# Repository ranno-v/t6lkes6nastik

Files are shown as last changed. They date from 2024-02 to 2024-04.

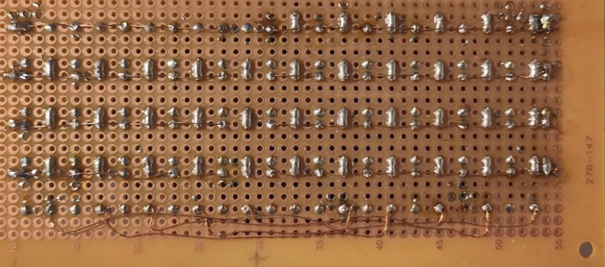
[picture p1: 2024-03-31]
klahvistiku_foto.png

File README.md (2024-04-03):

## Kirjeldus
See on gümnaasiumiastme praktilise töö "Ajaloolise kirjelduse põhjal Arduino UNO elektroonikaplatvormil loodud väike eesti-inglise-saksa-vene tõlkesõnastik" raames valminud projekti iseseisvaks sooritamiseks vajalike failide varamu. Siin asub Arduinole vajalik kood, korpuse ja nuppude 3D-printimiseks vajalikud STL-failid, joonised, tabelid, juhised jne. _Varamu on valmimisel._



## Komponendid
Seadme ehitamiseks vajalikud komponendid on Arduino Uno plaat, 16-segmendiline LCD-moodul DM8BA10, perforeeritud prototüüpplaat mõõtmetega vähemalt 45 x 20 auku (iga augu vahe 2.54 mm), 10 pistikutega juhet pikkusega vähemalt 20 cm (või 20 pistikuga juhet pikkusega vähemalt 10 cm, mille teises otsas on isoleerita traat), 44 mikrolülitit, 9-voldine patarei koos pesaga, 5,5 mm x 2,1 mm alalisvoolupistik (nn _barrel jack_), vasktraat, jootetina, 4 väikest kruvi, kiirliim, lüliti ja PLA-filament. Vajalikud tööriistad on 3D-printer, jootekolb, arvuti, USB-A/USB-B kaabel, akutrell ja lõikeriist, millega saab lõigata läbi prototüüpplaadi plastiku. Veel on vaja viisi seadmele klahvide märkimiseks, selleks sobib näiteks püsimarker või kleepepaber ja printer.

## Juhised
Esmalt lõigake 7 juhet pooleks ja puhastage lõigatud otsad isoleermaterjalist. Seejärel jootke mikrolülitid ja vasktraat prototüüpplaadi külge nii, nagu on näidatud joonistel klahvistiku_skeem.png ja klahvistiku_foto.png. Skeemil on vasktraat kujutatud punaste joontena ja jootetina roheliste joontena, lülitid pruunide ristkülikutena. Jootke juhtmete lõigatud otsad nummerdatud punaste ringidega märgitud kontaktide külge nii, et juhtmed väljuksid poolelt, kus pole kontakte. Numbritega on märgitud, millisesse Arduiino siini tuleb juhtme pistik panna. Lõigake perforeeritud plaadist ristkülik nii, et selle mõõtmed oleksid 45 x 20 auku (see ristkülik on skeemil märgitud punktiirjoonega). Asetage juhtmed skeemil märgitud siinidesse.

Lõigake pooleks veel 2 juhet ja puhastage lõigatud otsad isoleermaterjalist. Jootke juhtmed LCD-ekraani klemmide V+, G, D, WR ja CS külge ja asetage pistikud vastavalt siinidesse 5V, GND, A2, A1 ja A0.

Printige antud STL-failid välja. Kinnitage "klambrid" superliimiga plaadi külge nii, nagu on näidatud alloleval joonisel. Kinnitage LCD-ekraan superliimiga korpuse kaane külge. Puurige 2 mm puuriteraga läbi vertikaalsete osade ning kaane vastavate punktide augud nii, et mikrolülitid oleks kaanes olevate avadega kohakuti. Asetage klahvid avadesse ja kinnitage klambrid kruvidega kaane külge. Jootke 9V patarei alles jäänud juhtmetega läbi lüliti alalisvoolupistiku külge, tehke kaane sisse lüliti jaoks sobiv ava ja kinnitage lüliti kaane külge. Märgistage klahvid, selleks on üks võimalus printida välja fail labels.pdf, lõigata sildid mööda jooni nelja ribana välja ja liimida need kaane külge vastavate klahvide kohale. 



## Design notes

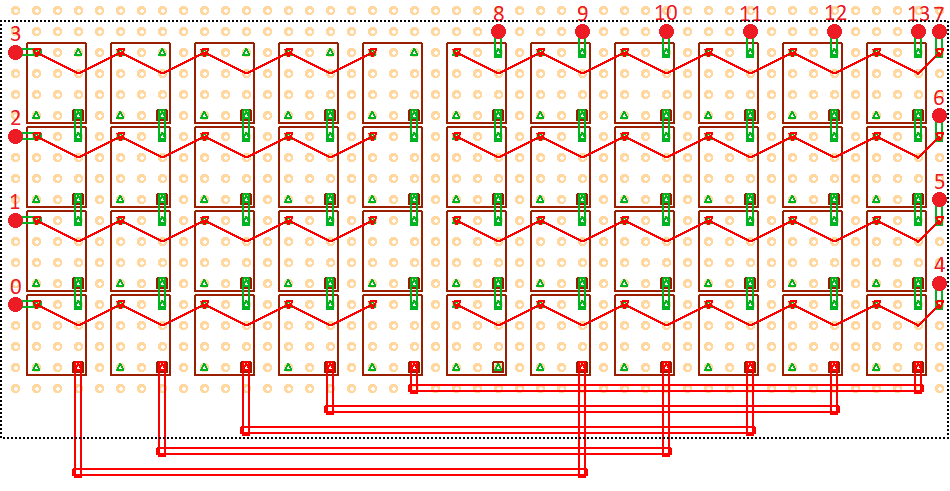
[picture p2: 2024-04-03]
kastiga_skeem.png

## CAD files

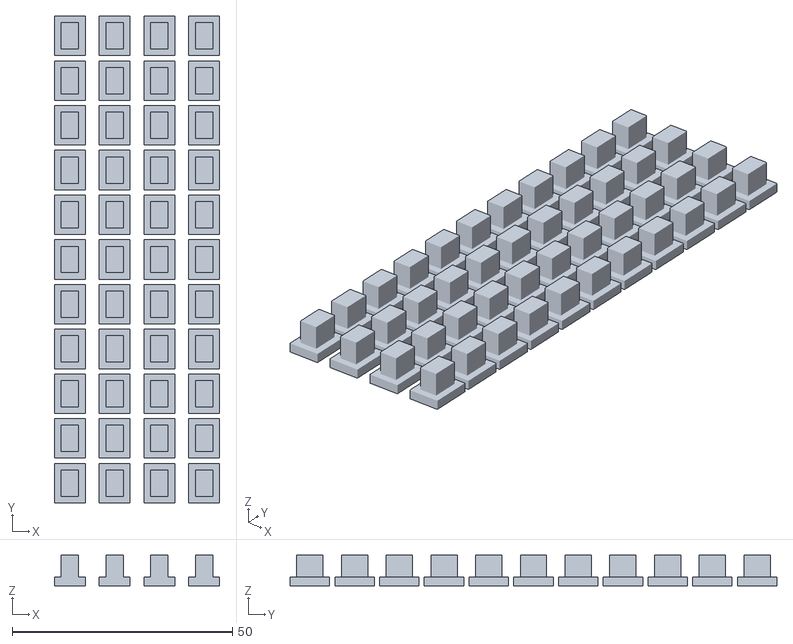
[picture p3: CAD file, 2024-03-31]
klahvid.stl
37.5 x 110.6 x 7.00

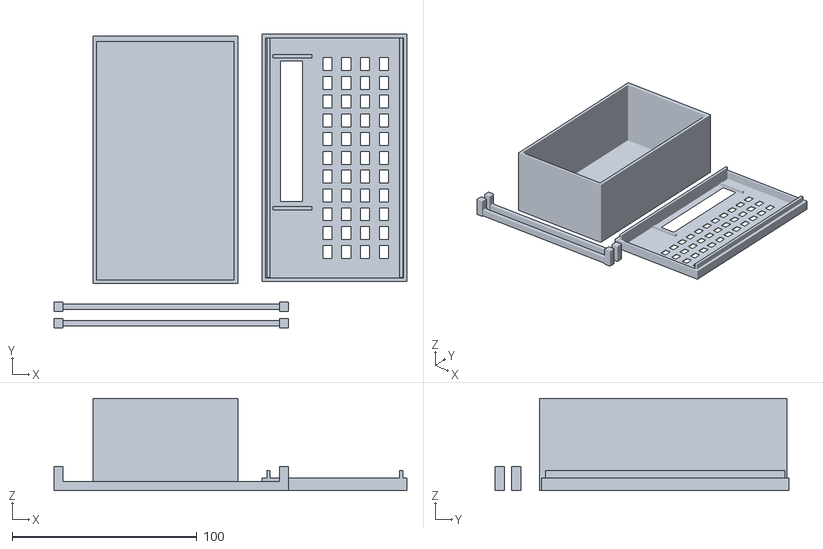
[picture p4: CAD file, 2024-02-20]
korpus.stl
191.0 x 159.0 x 50.0

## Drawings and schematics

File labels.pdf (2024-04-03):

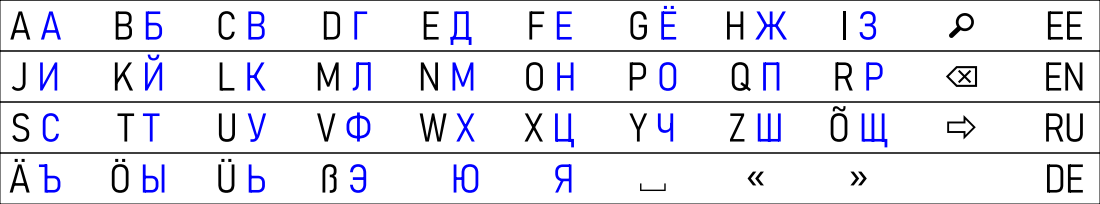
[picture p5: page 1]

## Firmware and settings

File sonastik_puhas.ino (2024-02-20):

#include <Keypad.h>
#define PGMT(pgm_ptr) ( reinterpret_cast< const __FlashStringHelper * >( pgm_ptr )

/*
=-=-=-=-=-=-=-=-=-=-=-=-=-=-=-=-=-=-=-=-=-=-=-=-=-=-=-=-=-=-=-=-=-=-=-=-=-=-=
    Arduino demo/driver for HT1622-based 16 segment LCDs

    Copyright (c) 2015-2021 Martin F. Falatic
    
    Licensed under the Apache License, Version 2.0 (the "License");
    you may not use this file except in compliance with the License.
    You may obtain a copy of the License at
    
        http://www.apache.org/licenses/LICENSE-2.0
    
    Unless required by applicable law or agreed to in writing, software
    distributed under the License is distributed on an "AS IS" BASIS,
    WITHOUT WARRANTIES OR CONDITIONS OF ANY KIND, either express or implied.
    See the License for the specific language governing permissions and
    limitations under the License.

=-=-=-=-=-=-=-=-=-=-=-=-=-=-=-=-=-=-=-=-=-=-=-=-=-=-=-=-=-=-=-=-=-=-=-=-=-=-=
Arduino is little-endian
H162x commands and addresses are MSB-first (3 bit mode + 9 bit command code)
Note that the very last bit is X (don't care)
Data is LSB-first, in address-sequential 4-bit nibbles as desired.
=-=-=-=-=-=-=-=-=-=-=-=-=-=-=-=-=-=-=-=-=-=-=-=-=-=-=-=-=-=-=-=-=-=-=-=-=-=-=
*/

//=-=-=-=-=-=-=-=-=-=-=-=-=-=-=-=-=-=-=-=-=-=-=-=-=-=-=-=-=-=-=-=-=-=-=-=-=-=-=
// Helper functions and variables
//=-=-=-=-=-=-=-=-=-=-=-=-=-=-=-=-=-=-=-=-=-=-=-=-=-=-=-=-=-=-=-=-=-=-=-=-=-=-=
#define ARRAY_SIZE(x) ((sizeof x) / (sizeof *x))

//=-=-=-=-=-=-=-=-=-=-=-=-=-=-=-=-=-=-=-=-=-=-=-=-=-=-=-=-=-=-=-=-=-=-=-=-=-=-=
// HT162x commands (Start with 0b100, ends with one "don't care" byte)
#define  CMD_SYS_DIS  0x00  // SYS DIS    (0000-0000-X) Turn off system oscillator, LCD bias gen [Default]
#define  CMD_SYS_EN   0x01  // SYS EN     (0000-0001-X) Turn on  system oscillator
#define  CMD_LCD_OFF  0x02  // LCD OFF    (0000-0010-X) Turn off LCD display [Default]
#define  CMD_LCD_ON   0x03  // LCD ON     (0000-0011-X) Turn on  LCD display
#define  CMD_RC_INT   0x18  // RC INT     (0001-10XX-X) System clock source, on-chip RC oscillator
#define  CMD_BIAS_COM 0x29  // BIAS & COM (0010-10X1-X) 1/3 bias, 4 commons // HT1621 only

#define  HT1622_ADDRS 0x40  // HT1622 has 64 possible 4-bit addresses

#define CS   14 // Active low
#define WR   15 // Active low
#define DATA  16

#define LSB_FORMAT  true
#define MSB_FORMAT  false

#define SETUP_DELAY_USECS 1
#define HOLD_DELAY_USECS  1
#define WRITE_DELAY_USECS 2  // Tclk min. on data sheet - overhead is more than this at low clock speeds
#define RESET_DELAY_USECS 1000  // Not strictly necessary

#define NUM_DIGITS  10

const uint8_t digitAddr[NUM_DIGITS] = {
  0x24, 0x20, 0x1C, 0x18, 0x14, 0x10, 0x0C, 0x08, 0x04, 0x00
};

const uint16_t PROGMEM SegCharDataLSBfirst[] = {
  0x0000, 0x0000, 0x122D, 0x0000, 0x0000, 0x0000, 0x0000, 0xCC0D, //  !"#$%&'
  0x0082, 0x2100, 0xA3A3, 0x8221, 0x0100, 0x8001, 0x0800, 0x0180, // ()*+,-./
  0x5C5C, 0x1A28, 0x9C59, 0x985D, 0xC045, 0xD81D, 0xDC1D, 0x1054, // 01234567
  0xDC5D, 0xD85D, 0x8800, 0x0000, 0x8809, 0x0000, 0x0000, 0x0000, // 89:;<=>?
  0x0000, 0x11D5, 0x1A3D, 0x4E28, 0x097C, 0x185D, 0xD271, 0x5410, // @ABCDEFG
  0x9D19, 0x45C4, 0x15C4, 0xC67C, 0x0174, 0x0000, 0x0000, 0x9C1D, // HIJKLMNO
  0x5454, 0xD155, 0x0000, 0x549D, 0xC045, 0x1C1C, 0x4E6E, 0x4E6C, // PQRSTUVW
  0x0000, 0xCE44, 0x23A2, 0x0000, 0x2002, 0x0000, 0x060D, 0x0808, // XYZ[\]^_
  0x0000, 0xD455, 0x1A7D, 0x5C18, 0x1A7C, 0xDC19, 0xD411, 0x5C1D, // `abcdefg
  0xC445, 0x1A38, 0x0C4C, 0xC482, 0x4C08, 0x64C4, 0x6446, 0x5C5C, // hijklmno
  0xD451, 0x5C5E, 0xD453, 0xD81D, 0x1230, 0x4C4C, 0x4580, 0x4546, // pqrstuvw
  0x2182, 0xC84D, 0x1998, 0x0000, 0x0000, 0x0000, 0x9CAD, 0x0000, // xyz{|}~
};

//=-=-=-=-=-=-=-=-=-=-=-=-=-=-=-=-=-=-=-=-=-=-=-=-=-=-=-=-=-=-=-=-=-=-=-=-=-=-=
char * valToHex(int val, int prec, const char * prefix) {
      static char fmt[32], output[32];
      sprintf(fmt, "%s%%0%dX", prefix, prec);
      sprintf(output, fmt, val);
      return output;
}

//=-=-=-=-=-=-=-=-=-=-=-=-=-=-=-=-=-=-=-=-=-=-=-=-=-=-=-=-=-=-=-=-=-=-=-=-=-=-=
// Send up to 16 bits, MSB (default) or LSB
//=-=-=-=-=-=-=-=-=-=-=-=-=-=-=-=-=-=-=-=-=-=-=-=-=-=-=-=-=-=-=-=-=-=-=-=-=-=-=
void HT162x_SendBits(uint16_t data, uint8_t bits, boolean LSB_FIRST = MSB_FORMAT)
{
  // Data is shifted out bitwise, either LSB-first or MSB-first.
  // The mask is used to isolate the bit being transmitted.

  uint16_t mask = LSB_FIRST ? 1 : 1 << bits-1;

  for (uint8_t i = bits; i > 0; i--)
  {
    delayMicroseconds(WRITE_DELAY_USECS);
    digitalWrite(WR, LOW);
    data & mask ? digitalWrite(DATA, HIGH) : digitalWrite(DATA, LOW);
    delayMicroseconds(WRITE_DELAY_USECS);
    digitalWrite(WR, HIGH);
    delayMicroseconds(HOLD_DELAY_USECS);
    LSB_FIRST ? data >>= 1 : data <<= 1;
  }
}

//=-=-=-=-=-=-=-=-=-=-=-=-=-=-=-=-=-=-=-=-=-=-=-=-=-=-=-=-=-=-=-=-=-=-=-=-=-=-=
void HT162x_Command(uint8_t cmd)
{
  delayMicroseconds(SETUP_DELAY_USECS);
  digitalWrite(CS, LOW);
  delayMicroseconds(SETUP_DELAY_USECS);
  HT162x_SendBits(0b100, 3);
  HT162x_SendBits(cmd, 8);
  HT162x_SendBits(1, 1);
  delayMicroseconds(SETUP_DELAY_USECS);
  digitalWrite(CS, HIGH);
}

//=-=-=-=-=-=-=-=-=-=-=-=-=-=-=-=-=-=-=-=-=-=-=-=-=-=-=-=-=-=-=-=-=-=-=-=-=-=-=
void HT162x_WriteData(uint8_t addr, uint16_t sdata, uint8_t bits = 4)
{
  // Note: bits needs to be a multiple of 4 as data is in nibbles
  delayMicroseconds(SETUP_DELAY_USECS);
  digitalWrite(CS, LOW);
  delayMicroseconds(SETUP_DELAY_USECS);
  HT162x_SendBits(0b101, 3);
  HT162x_SendBits(addr, 6);
  for (int n = (bits/4)-1; n >= 0; n--) {
    uint16_t nib = (sdata & (0xf) << 4*n) >> (4*n);
    HT162x_SendBits(nib, 4, LSB_FORMAT);
  }
  delayMicroseconds(SETUP_DELAY_USECS);
  digitalWrite(CS, HIGH);
}

void AllElements(uint8_t state)
{
  for (uint8_t addr = 0; addr < HT1622_ADDRS; addr++)
  {
    HT162x_WriteData(addr, (state ? 0xF : 0x0), 4);
  }
}

void AllSegments(uint8_t state)
{
  for (uint8_t pos = 0; pos < NUM_DIGITS; pos++)
  {
    HT162x_WriteData(digitAddr[pos], (state ? 0xFFFF : 0x0000), 16);
  }
}

void Display(char word[], int word_len, int position)
{
  for (int n = 0; n + position < word_len && n < 10 ; n++)
  {
    HT162x_WriteData(digitAddr[n], pgm_read_word_near(SegCharDataLSBfirst + (int)word[n + position] - 32), 16);
  }

}

// END OF LCD DRIVER FUNCTIONS

const byte rows = 8;  // eight rows
const byte cols = 6;  // six columns
char keys[rows][cols] = {
  {  1,  2,  3,  4,  5,  6, },
  { 10, 11, 12, 13, 14, 15, },
  { 19, 20, 21, 22, 23, 24, },
  { 28, 29, 30, 31, 32, 33, },

  {  7,  8,  9,  37,  41,  0, },
  { 16, 17, 18,  38,  42,  0, },
  { 25, 26, 27,  39,  43,  0, },
  { 34, 35, 36,  40,  44,  0, },
};
byte rowPins[rows] = { 13, 12, 11, 10, 9, 8, 7, 6, };        // connect to the row pinouts of the keypad
byte colPins[cols] = { 5, 4, 3, 2, 1, 0, };  // connect to the column pinouts of the keypad
Keypad keyboard = Keypad(makeKeymap(keys), rowPins, colPins, rows, cols);

const char latin[34] =    "abcdefghijklmnopqrstuvwxyz~AOUS   ";
const char cyrillic[34] = "aBbGDeHZ3IJkLmhoPpctyFxCTWV\"Y\'EKQ ";

const char PROGMEM estonian[] = "\naasta\nabi\naeg\naga\nainult\nainus\naitama\najal\najama\naken\naktsia\nalati\nalgama\nalgus\nall\nalla\nalles\nalus\nalustama\namet\nandma\nandmed\naru\narvama\nasi\nastuma\nasuma\naugust\nauto\navama\nedasi\neelmine\nees\neesmArk\neest\neesti\neestlane\nega\nehitama\nehk\nei\neile\neks\nelama\nelu\nema\nenam\nendine\nenne\nent\nerakond\nerinev\neriti\nesimees\nesimene\nesitama\net\nette\nettev~te\nfilm\nfirma\nhakkama\nhea\nheitma\nhetk\nhiljem\nhind\nhing\nhinnang\nhoidma\nhommik\nhoopis\nhulk\nhuvi\nhAsti\nhAAl\niga\nikka\nikkagi\nilm\nilma\nilmselt\nilmuma\nilus\ninimene\nisa\nise\nisegi\nistuma\nja\njah\njalg\njaoks\njooksma\njooksul\nju\njuba\njuhataja\njuht\njuhtuma\njumal\njust\njutt\njuurde\njuures\nj~ud\nj~udma\njAlle\njArel\njArele\njArgi\njArgmine\njAtkama\njAtma\njAAma\nka\nkaasa\nkaduma\nkaks\nkandma\nkaotama\nkartma\nkas\nkasutama\nkasvama\nkeegi\nkeel\nkeha\nkell\nkes\nkiiresti\nkindel\nkindlasti\nkinni\nkinnitama\nkiri\nkirjutama\nkodu\nkoer\nkogu\nkohalik\nkohe\nkoht\nkohta\nkohus\nkokku\nkolm\nkolmas\nkool\nkoos\nkord\nkorraldama\nkorter\nkostma\nkroon\nkuhu\nkui\nkuid\nkuidagi\nkuidas\nkuigi\nkuna\nkunagi\nkuni\nkus\nkust\nkutsuma\nkuu\nkuulama\nkuulma\nkuuluma\nk~ige\nk~ik\nk~rge\nk~rval\nk~rvale\nkAima\nkAsi\nkUll\nkUlm\nkUmme\nkUsima\nkUsimus\nlaev\nlahkuma\nlahti\nlangema\nlaps\nlaskma\nlaud\nlausuma\nleidma\nleping\nligi\nlihtsalt\nliiga\nliige\nliikuma\nliit\nlinn\nlisa\nlisama\nlooma\nlootma\nlubama\nlugema\nlugu\nl~petama\nl~pp\nl~ppema\nl~puks\nlAbi\nlOOma\nmaa\nmaailm\nmagama\nmaha\nmaja\nmaksma\nmeel\nmeeldima\nmeenutama\nmees\nmeri\nmets\nmiks\nmiljon\nmilline\nmina\nminema\nmingi\nmis\nmiski\nmitte\nmitu\nmuidu\nmuidugi\nmust\nmuu\nmuutma\nmuutuma\nm~istma\nm~lema\nm~ni\nm~te\nm~tlema\nmAletama\nmAng\nmAngima\nmArkama\nmArkima\nmArts\nmOOda\nmUUma\nnaerma\nnagu\nnaine\nneli\nnii\nniisugune\nnimetama\nnimi\nning\nnoor\nnoormees\nn~nda\nn~udma\nn~ukogu\nnAdal\nnAgema\nnAgu\nnAima\nnAitama\nnAiteks\nnUUd\nolema\nolev\nolukord\noluline\noma\nomanik\nometi\nootama\nosa\noskama\nostma\notsa\notse\notsima\notsus\notsustama\npaar\npaistma\npakkuma\npalju\npalk\npaluma\npanema\npank\nparem\nparim\npea\npeaaegu\npeale\npeaminister\npidama\npiir\npikk\npilk\npilt\npisut\npoeg\npoiss\npoliitiline\npolitsei\npool\npoole\npraegu\npraegune\npresident\nprobleem\nprotsent\npuhas\npuhul\npunane\npuu\np~hjus\npAev\npArast\npAris\npAAsema\npOOrama\npOOrduma\npUUdma\nraamat\nraha\nrahvas\nraske\nriigikogu\nriik\nringi\nrohkem\nruum\nrAAkima\nsaama\nsaatma\nsama\nsamas\nsamm\nsamuti\nsattuma\nseadus\nseal\nsealt\nsee\nsein\nseisma\nselg\nselge\nselgitama\nselline\nseni\nsest\nsiduma\nsiia\nsiin\nsiis\nsiiski\nsilm\nsina\nsinna\nsisse\nsoovima\nsuhe\nsurm\nsuu\nsuur\nsuurem\nsuutma\nsuvi\ns~ber\ns~itma\ns~na\nsOOma\nsUda\nsUndima\ntaas\ntaga\ntagasi\ntaha\ntahtma\nteadma\nteatama\ntee\ntegelikult\ntegema\ntegemine\ntegevus\nteine\ntekkima\ntema\nterve\ntoetama\ntohtima\ntoimuma\ntoo\ntooma\ntuba\ntuhat\ntulema\ntulemus\ntuli\ntund\ntundma\ntunduma\ntunne\ntunnistama\nturg\ntuttav\ntuul\nt~esti\nt~mbama\nt~stma\nt~ttu\nt~usma\ntAhendama\ntAiesti\ntAis\ntAitma\ntAna\ntAnav\ntApselt\ntOO\ntOOtaja\ntOOtama\ntUdruk\ntUhi\ntUtar\nuks\numbes\nuskuma\nuuesti\nuurima\nuus\nvaatama\nvaba\nvahel\nvahele\nvaid\nvaja\nvajalik\nvajama\nvalge\nvalima\nvalimine\nvalitsus\nvalmis\nvana\nvanem\nvarem\nvastama\nvastu\nvastus\nveel\nveidi\nvene\nvesi\nviima\nviimane\nviis\nvist\nv~i\nv~ib-olla\nv~ima\nv~imalik\nv~imalus\nv~itma\nv~tma\nv~~ras\nvAga\nvAhem\nvAhemalt\nvAike\nvAitma\nvAlja\n~hk\n~htu\n~ige\n~igus\n~nn\n~petaja\n~ppima\nAkki\nAra\nOO\nUks\nUldse\nUle\nUles\nUlikool\nUmber\nUsna\nUtlema\n";
const int estonian_numbers[] = { };
const char PROGMEM english[] = "\na little 1\na little 2\na lot\nabout 1\nabout 2\nabsolutely\naccording to\naction\nactually\nadd 1\nadd 2\nadmit\nafter 1\nafter 2\nafter 3\nafter all\nagain 1\nagain 2\nagain 3\nagainst\nage\nahead\nair\nallow\nalmost\nalready\nalthough\nalways\namount\nand 1\nand 2\nanother\nanswer 1\nanswer 2\nanymore\nanyway\napartment\napparently\nappear 1\nappear 2\nappear 3\narise\naround 1\naround 2\narrange\nas well\naside\nask 1\nask 2\nassessment\nat 1\nat 2\nat all\nat least\naugust\naway\nback 1\nback 2\nbank\nbasis\nbe\nbe able to 1\nbe able to 2\nbe afraid of\nbe allowed\nbe born\nbe heard\nbeautiful\nbecause 1\nbecause 2\nbecause of\nbefore\nbegin\nbeginning\nbehind 1\nbehind 2\nbelieve\nbelong to\nbelow\nbeside\nbest\nbetter\nbetween\nbigger\nbind\nblack\nbody\nbook\nborder\nboth\nboy\nbring\nbuild\nbut 1\nbut 2\nbut 3\nbuy\ncall\ncame\ncar\ncase\ncast\ncatch\ncertain\nchairman\nchange 1\nchange 2\nchild\nchoose\nchoosing\ncity\nclaim\nclean\nclear\nclose to\nclosed\ncold\ncollection\ncome\ncompany 1\ncompany 2\nconfirm\ncontinue\ncontract\ncorrect\ncouncil\ncountry\ncouple\ncourt\ncreate\ncrown\ncurrent one\ndata\ndaughter\nday\ndeath\ndecide\ndecision\ndefinitely\ndemand\ndifferent\ndifficult\ndirectly\ndo\ndog\ndoor\ndown 1\ndown 2\ndrive 1\ndrive 2\nduring 1\nduring 2\nearlier\neat\neither\nemployee\nempty\nend 1\nend 2\nend 3\nescape\nespecially\nestonian 1\nestonian 2\neven\nevening\never\neverything 1\neverything 2\nexactly 1\nexactly 2\nexplain\neye\nface\nfall\nfamiliar\nfast\nfather\nfeel\nfeeling\nfinally\nfind\nfirst\nfive\nfor 1\nfor 2\nfor example\nforest\nformer\nforward\nfour\nfree\nfriend\nfrom there\nfrom where\nfulfill\nfull\ngame\nget\nget into\nget up\ngirl\ngive\ngo\ngo away\ngod\ngood\ngovernment\ngrow\nhand\nhandle it\nhappen\nhead\nhealthy\nhear\nheart\nhelp 1\nhelp 2\nhere 1\nhere 2\nhigh\nhim\nhimself\nhit\nhome\nhope\nhour\nhouse\nhow\nhowever 1\nhowever 2\nhowever 3\nhuman\ni guess\nif\nimmediately\nimportant\nin\nin front\ninstead\ninterest\ninvestigate\nkeep 1\nkeep 2\nknow\nland\nlanguage\nlarge\nlast one\nlater\nlaugh\nlaw\nlearn\nleave 1\nleave 2\nleg\nless\nlet\nletter\nlife\nlift\nlike 1\nlike 2\nlike that\nlike this\nlisten\nlive\nlocal\nlong\nlook\nlook for\nlose\nluck\nmaking\nman\nmanager 1\nmanager 2\nmarch\nmarket\nme\nmean\nmember\nmillion\nmind\nmoment\nmoney\nmonth\nmore\nmorning\nmother\nmouth\nmove\nmovie\nmultiple\nname 1\nname 2\nnation\nnecessary\nneed 1\nneed 2\nnew\nnext\nnight\nno\nnor\nnot\nnote\nnotice\nnow\nof course\noffer\nold\non\none\nonly 1\nonly 2\nopen 1\nopen 2\nopportunity\nor\notherwise\nout\nover\nown\nowner\nparent\nparliament\npart\nparty\npast\npay\npercentage\nperhaps 1\nperhaps 2\npicture\nplace\nplay\npolice\npolitical\npossible\npower 1\npower 2\npresent 1\npresent 2\npresident\nprevious\nprice\nprime minister\nproblem\nprofession\npull\npurpose\nput\nquestion\nquite\nreach\nread\nready\nreal\nreally\nreason\nred\nrelationship\nremember 1\nremember 2\nreport\nresult\nright 1\nright 2\nright now\nroad\nroom 1\nroom 2\nrun\nrussian\nsalary\nsame\nsay\nschool\nsea\nsee 1\nsee 2\nseem\nsell 1\nsell 2\nsend\nsettle down\nship\nshow\nside\nsimply\nsit down\nsituation\nsleep\nsmall\nso\nso far\nsome\nsome kind\nsomehow\nsomeone\nsomething\nsometimes\nson\nsoul\nstand\nstart\nstay\nstep 1\nstep 2\nstill 1\nstill 2\nstock\nstop\nstory\nstranger\nstreet\nsuch\nsuddenly\nsummer\nsupport\ntable\ntake 1\ntake 2\ntake place\ntalk 1\ntalk 2\nteacher\nten\nthat 1\nthat 2\nthen\nthere 1\nthere 2\nthing\nthink 1\nthink 2\nthird\nthis\nthough\nthought\nthousand\nthree\nthrough\ntime 1\ntime 2\nto\ntoday\ntogether 1\ntogether 2\ntoo 1\ntoo 2\ntowards\ntree\nturn 1\nturn 2\ntwo\nunderstand\nunderstood\nunion\nuniversity\nuntil\nup\nuse\nutter\nwait\nwall\nvanish\nwant to\nwater\nwear\nweather\nweek\nwell\nvery\nwhat\nwhere 1\nwhere 2\nwhich one\nwhite\nwho\nwhy\nwin\nwind\nwindow\nwish\nwith\nwithout\nvoice\nwoman\nword\nwork 1\nwork 2\nworld\nwrite\nyear\nyes\nyesterday\nyet 1\nyet 2\nyou\nyoung\nyoung man\n";
const int PROGMEM english_numbers[] = { 310, 464, 294, 143, 439, 426, 110, 397, 394, 200, 201, 416, 108, 109, 328, 95, 107, 386, 441, 461, 76, 57, 485, 204, 302, 96, 160, 11, 72, 89, 262, 398, 460, 462, 46, 78, 152, 81, 82, 271, 292, 399, 340, 500, 151, 349, 175, 181, 296, 68, 104, 128, 496, 481, 27, 493, 357, 388, 298, 17, 275, 284, 378, 121, 403, 385, 153, 83, 161, 362, 423, 48, 12, 13, 387, 389, 440, 170, 14, 174, 300, 299, 447, 377, 363, 237, 127, 334, 306, 242, 312, 406, 38, 3, 157, 448, 285, 166, 411, 28, 323, 63, 333, 131, 53, 239, 240, 187, 453, 454, 199, 483, 322, 358, 193, 133, 179, 139, 409, 58, 60, 134, 112, 192, 487, 267, 339, 291, 144, 202, 154, 318, 21, 437, 327, 374, 290, 289, 132, 266, 51, 337, 287, 395, 138, 438, 15, 216, 8, 381, 7, 94, 459, 383, 122, 433, 436, 208, 209, 286, 330, 52, 35, 36, 87, 486, 162, 171, 172, 101, 431, 359, 368, 270, 186, 418, 130, 85, 413, 415, 210, 191, 54, 469, 34, 92, 273, 224, 47, 30, 257, 445, 380, 353, 165, 428, 427, 247, 344, 350, 424, 435, 20, 176, 229, 100, 62, 455, 124, 177, 61, 99, 301, 401, 169, 384, 1, 6, 364, 365, 173, 400, 86, 212, 137, 203, 412, 217, 159, 49, 347, 367, 84, 470, 156, 141, 278, 371, 32, 71, 73, 442, 69, 305, 391, 213, 126, 376, 468, 65, 254, 351, 491, 113, 184, 91, 480, 188, 135, 44, 422, 220, 255, 259, 265, 168, 43, 140, 307, 308, 288, 120, 489, 396, 222, 97, 98, 251, 417, 228, 425, 196, 226, 219, 64, 335, 167, 341, 70, 45, 375, 197, 59, 234, 260, 261, 336, 450, 449, 451, 443, 111, 494, 40, 37, 233, 250, 249, 274, 236, 293, 457, 303, 495, 4, 5, 29, 185, 475, 471, 235, 484, 497, 279, 280, 458, 338, 283, 50, 252, 218, 321, 39, 472, 309, 142, 248, 314, 313, 474, 105, 473, 55, 276, 319, 31, 66, 304, 320, 19, 421, 33, 297, 182, 501, 106, 205, 456, 329, 420, 326, 324, 373, 221, 246, 392, 410, 42, 488, 317, 393, 342, 407, 93, 465, 295, 346, 502, 148, 223, 269, 444, 414, 238, 253, 345, 26, 183, 272, 315, 194, 88, 277, 215, 482, 258, 361, 243, 230, 158, 125, 232, 446, 311, 67, 356, 18, 114, 25, 348, 16, 77, 10, 207, 206, 478, 430, 360, 492, 379, 402, 189, 467, 477, 404, 102, 343, 490, 180, 56, 405, 366, 352, 370, 24, 23, 245, 147, 354, 178, 244, 408, 146, 211, 2, 150, 103, 429, 145, 149, 115, 195, 316, 325, 331, 332, 118, 241, 22, 198, 499, 163, 498, 123, 190, 282, 355, 117, 390, 466, 119, 79, 268, 74, 479, 231, 155, 164, 227, 452, 129, 225, 476, 419, 9, 372, 116, 80, 75, 256, 382, 432, 434, 214, 136, 0, 90, 41, 281, 463, 369, 263, 264, };
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
void loop() {
  // put your main code here, to run repeatedly:
  static char x;
  x = 0;

  while (x == 0) {
    x = keyboard.getKey();
  }

  switch(x) {
    case 1 ... 34:
      if (search == 1) {
        if (ext_word_len >= 29) {
          ext_word[0] = '\0';
          ext_word_len = 0;
          position = 0;
          break;
        }
        if (language == russian) {
          addCharToStr(cyrillic[x - 1], ext_word, &ext_word_len);
        } else {
          addCharToStr(latin[x - 1], ext_word, &ext_word_len);
        }

        if (ext_word_len > 10) {
          position++;
        }
      }
    break;

    case 35:
      if (search == 0) {
        makeLastWord(ext_word, &ext_word_len, language, language_len);
        position = 0;
      }
    break;

    case 36:
      if (search == 0) {
        makeNextWord(ext_word, &ext_word_len, language, language_len);
        position = 0;
      }
    break;

    case 37:
      if (search == 0) {
        search = 1;
        ext_word[0] = '\0';
        ext_word_len = 0;
        position = 0;
      } else {
        alphFinder(ext_word, ext_word_len, ext_word, &ext_word_len, language, language_len);
        if (ext_word_len > 0) {
          search = 0;
        }
        position = 0;
      }
    break;

    case 38:
      if (search == 1) {
        if (position > 0) {
          position--;
        }
        if (ext_word_len > 0) {
          ext_word[ext_word_len - 1] = '\0';
          ext_word_len--;
        }
      } else {
        position = 0;
      }
    break;

    case 39:
      if (search == 0) {
        if (ext_word_len > position + 10) {
          position++;
        }
      }

    break;

    case 41 ... 44:
      prev_language = language;
      prev_len = language_len;
      prev_numbers = language_numbers;

      switch(x) {
        case 41:
          language = estonian;
          language_len = ESTONIAN_LEN;
          language_numbers = estonian_numbers;
        break;
        case 42:
          language = english;
          language_len = ENGLISH_LEN;
          language_numbers = english_numbers;
        break;
        case 43:
          language = russian;
          language_len = RUSSIAN_LEN;
          language_numbers = russian_numbers;
        break;
        case 44:
          language = german;
          language_len = GERMAN_LEN;
          language_numbers = german_numbers;
        break;
      }
      if (search == 0) { 
        translate(ext_word, &ext_word_len, prev_language, prev_len, prev_numbers, language, language_len, language_numbers);
        position = 0;
      } else {
        ext_word[0] = '\0';
        ext_word_len = 0;
        position = 0;
      }
    break;
  }

  AllSegments(0);
  Display(ext_word, ext_word_len, position);

}
